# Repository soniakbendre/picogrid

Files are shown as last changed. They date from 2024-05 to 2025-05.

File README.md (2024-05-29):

# Picogrid

[Maitreyee Marathe](maitreyeemarathe23@gmail.com), [Varun Balan](varunbalan30@gmail.com), Prof. Giri Venkataramanan   
University of Wisconsin-Madison

## Overview
The Picogrid is a low-cost low-power experimental platform for energy access and energy management modeling needs. The Picogrid platform consists of three layers, viz., Pico boards, a cloud dashboard, and a remote node as seen in the image below. 

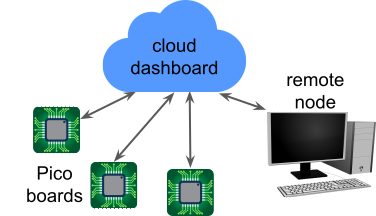
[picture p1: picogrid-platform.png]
Picogrid Platform


These layers together form a small benchtop microgrid or a "picogrid" and emulate their real-world counterparts. Pico boards emulate prosumer households. The remote node emulates a load serving entity, DERMS (distributed energy resource management system), or a microgrid operator which can provide operating set points to the prosumers. The cloud dashboard emulates the data transfer system between the prosumers and the operator.  

## File organization
* pcb-files - contains Gerber files for building Pico boards and add-on modules
* embedded-software - code for Particle microcontroller on the Pico board
* cloud-dashboard - code for setting up cloud dashboard
* remote-node - contains sample code for sending setpoints from a remote node to the cloud dashboard

## Citation
Link and citation for our publication: [Picogrid: An experimental platform for prosumer microgrids](https://ieeexplore.ieee.org/abstract/document/10362891)   
```
@inproceedings{marathe2023picogrid,   
  title={Picogrid: An experimental platform for prosumer microgrids},   
  author={Marathe, Maitreyee and Venkataramanan, Giri},   
  booktitle={2023 IEEE Energy Conversion Congress and Exposition (ECCE)},   
  pages={718--725},   
  year={2023},   
  organization={IEEE}   
}
```

## Acknowledgments
We would like to thank Gabriela
Setyawan, Savannah Ahnen, and Shreya Mukherjee for their help in developing and testing the platform. This work was supported by the George Bunn Wisconsin Distinguished Graduate Fellowship provided by the University of Wisconsin-Madison and the Wisconsin Electric Machines and Power Electronics Consortium.

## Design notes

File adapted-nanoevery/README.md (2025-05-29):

# adapted-nanoevery

This firmware project was created using [Particle Developer Tools](https://www.particle.io/developer-tools/) and is compatible with all [Particle Devices](https://www.particle.io/devices/).

Feel free to replace this README.md file with your own content, or keep it for reference.

## Table of Contents
- [Introduction](#introduction)
- [Prerequisites To Use This Template](#prerequisites-to-use-this-repository)
- [Getting Started](#getting-started)
- [Particle Firmware At A Glance](#particle-firmware-at-a-glance)
  - [Logging](#logging)
  - [Setup and Loop](#setup-and-loop)
  - [Delays and Timing](#delays-and-timing)
  - [Testing and Debugging](#testing-and-debugging)
  - [GitHub Actions (CI/CD)](#github-actions-cicd)
  - [OTA](#ota)
- [Support and Feedback](#support-and-feedback)
- [Version](#version)

## Introduction

For an in-depth understanding of this project template, please refer to our [documentation](https://docs.particle.io/firmware/best-practices/firmware-template/).

## Prerequisites To Use This Repository

To use this software/firmware on a device, you'll need:

- A [Particle Device](https://www.particle.io/devices/).
- Windows/Mac/Linux for building the software and flashing it to a device.
- [Particle Development Tools](https://docs.particle.io/getting-started/developer-tools/developer-tools/) installed and set up on your computer.
- Optionally, a nice cup of tea (and perhaps a biscuit).

## Getting Started

1. While not essential, we recommend running the [device setup process](https://setup.particle.io/) on your Particle device first. This ensures your device's firmware is up-to-date and you have a solid baseline to start from.

2. If you haven't already, open this project in Visual Studio Code (File -> Open Folder). Then [compile and flash](https://docs.particle.io/getting-started/developer-tools/workbench/#cloud-build-and-flash) your device. Ensure your device's USB port is connected to your computer.

3. Verify the device's operation by monitoring its logging output:
    - In Visual Studio Code with the Particle Plugin, open the [command palette](https://docs.particle.io/getting-started/developer-tools/workbench/#particle-commands) and choose "Particle: Serial Monitor".
    - Or, using the Particle CLI, execute:
    ```
    particle serial monitor --follow
    ```

4. Uncomment the code at the bottom of the cpp file in your src directory to publish to the Particle Cloud! Login to console.particle.io to view your devices events in real time.

5. Customize this project! For firmware details, see [Particle firmware](https://docs.particle.io/reference/device-os/api/introduction/getting-started/). For information on the project's directory structure, visit [this link](https://docs.particle.io/firmware/best-practices/firmware-template/#project-overview).

## Particle Firmware At A Glance

### Logging

The firmware includes a [logging library](https://docs.particle.io/reference/device-os/api/logging/logger-class/). You can display messages at different levels and filter them:

```
Log.trace("This is trace message");
Log.info("This is info message");
Log.warn("This is warn message");
Log.error("This is error message");
```

### Setup and Loop

Particle projects originate from the Wiring/Processing framework, which is based on C++. Typically, one-time setup functions are placed in `setup()`, and the main application runs from the `loop()` function.

For advanced scenarios, explore our [threading support](https://docs.particle.io/firmware/software-design/threading-explainer/).

### Delays and Timing

By default, the setup() and loop() functions are blocking whilst they run, meaning that if you put in a delay, your entire application will wait for that delay to finish before anything else can run. 

For techniques that allow you to run multiple tasks in parallel without creating threads, checkout the code example [here](https://docs.particle.io/firmware/best-practices/firmware-template/).

(Note: Although using `delay()` isn't recommended for best practices, it's acceptable for testing.)

### Testing and Debugging

For firmware testing and debugging guidance, check [this documentation](https://docs.particle.io/troubleshooting/guides/build-tools-troubleshooting/debugging-firmware-builds/).

### GitHub Actions (CI/CD)

This project provides a YAML file for GitHub, automating firmware compilation whenever changes are pushed. More details on [Particle GitHub Actions](https://docs.particle.io/firmware/best-practices/github-actions/) are available.

### OTA

To learn how to utilize Particle's OTA service for device updates, consult [this documentation](https://docs.particle.io/getting-started/cloud/ota-updates/).

Test OTA with the 'Particle: Cloud Flash' command in Visual Studio Code or the CLI command 'particle flash'!

This firmware supports binary assets in OTA packages, allowing the inclusion of audio, images, configurations, and external microcontroller firmware. More details are [here](https://docs.particle.io/reference/device-os/api/asset-ota/asset-ota/).

## Support and Feedback

For support or feedback on this template or any Particle products, please join our [community](https://community.particle.io)!

## Version

Template version 1.0.2

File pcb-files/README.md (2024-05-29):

## Pico board PCB
The image below shows the Pico board with the major sections labelled.   
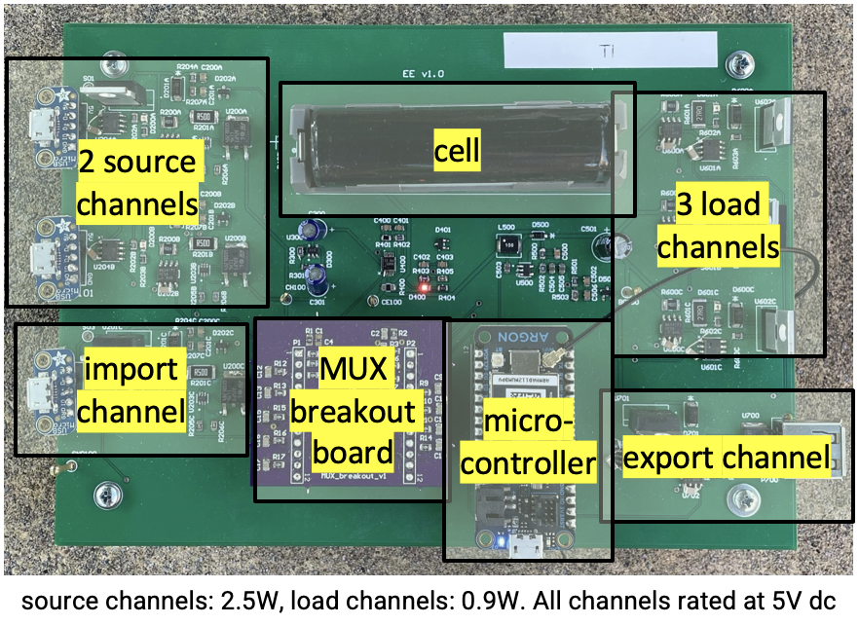
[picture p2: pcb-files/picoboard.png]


## File Organization
* pico-board - files for the Pico board
* mux-breakout - files for the MUX breakout board that is plugged into the Pico board
* junction-board - files for the board used to interconnect Pico boards

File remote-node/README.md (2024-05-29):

The remote node can be any system with an internet connection, not necessarily co-located with the Pico boards.
* send-setpoints.jl - contains sample code in Julia that can be implemented on a remote node to send setpoints to a Pico board

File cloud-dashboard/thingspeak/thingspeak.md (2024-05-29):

To use Mathworks ThingSpeak to develop the cloud dashboard:
* Each ThingSpeak channel can store and display up to 8 fields. Create multiple channels per Pico board if more than 8 fields are needed.
* The write API keys of the channels need to be added to the embedded code for Pico boards to send data to the channel. 
* If Pico boards need to read data from channels, read API keys of the channels are to be added to the embedded code.

More information can be found [here](https://www.mathworks.com/help/thingspeak/).

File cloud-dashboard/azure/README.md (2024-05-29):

This platform is a web application developed with Python (+ [Flask](https://flask.palletsprojects.com/en/3.0.x/)) which interacts with [Particle Argon](https://docs.particle.io/argon/) boards (microcontrollers used in our hardware platform) and [Microsoft Azure](https://azure.microsoft.com/en-us) (the cloud provider used to develop to develop the platform)

## Folder structure
- **app.py**: the main backend code logic which decides what parts of the app the user sees based on user interaction
- **requirements.txt**: list of all the packages that were used in the project. Will use `pip` to download all the packages at once
- **static**: a temporary store to hold the data which the user retrieves and the plots that are generated (the files within these are deleted on each refresh of the app)
- **templates**: HTML pages with [Jinja](https://jinja.palletsprojects.com/en/3.1.x/) templating to dynamically show content based on user interaction with platform

## Cloud Dashboard Screenshots
The image below shows the data retrieval page of the dashboard. Users can get data out from specific Pico boards based on the time frames of their experiment in CSV format for further analysis.   
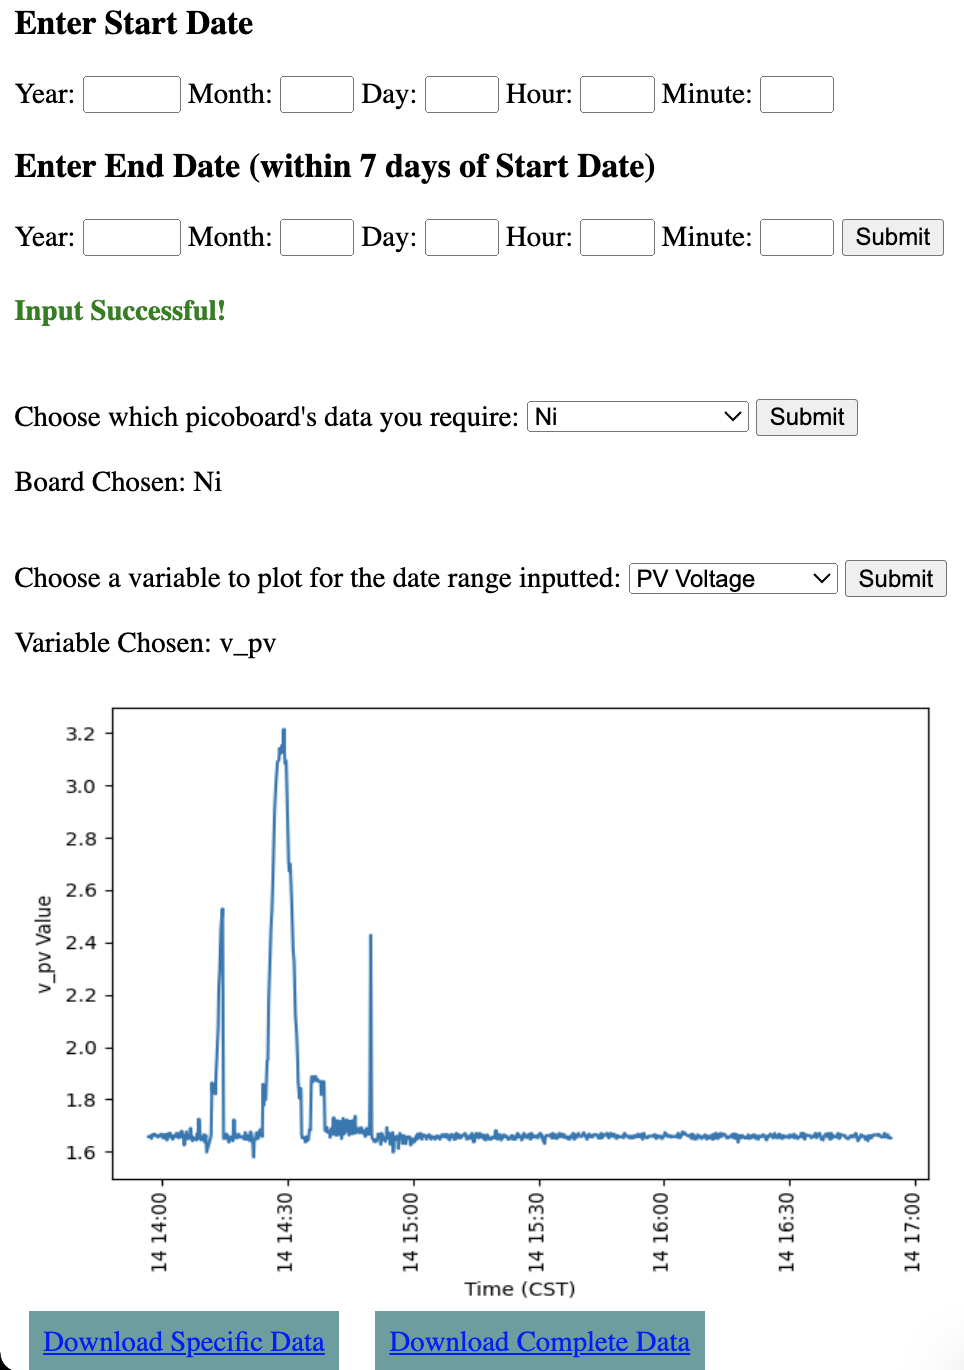
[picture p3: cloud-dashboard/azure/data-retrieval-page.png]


The image below shows the page that can be used to send setpoints (such as thresholds to actuate loads and sources) from the dashboard to the Pico boards. This enables users to make dynamic changes with minimal latency during experiments.   
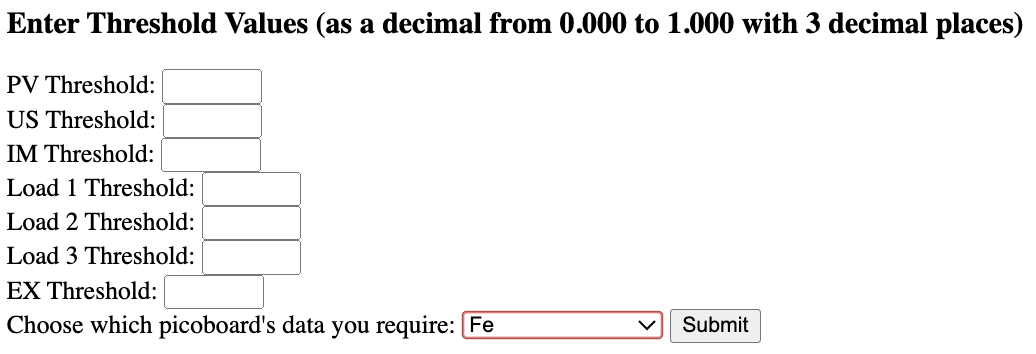
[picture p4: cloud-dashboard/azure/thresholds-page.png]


## Setup
1. After downloading the code and [having pip installed](https://pypi.org/project/pip/), navigate to the folder in Terminal / PowerShell and run `pip install -r requirements.txt` to download all packages
2. Set up Azure IoT Hub and a Particle Integration to connect the Particle Argon to Azure using these [instructions](https://docs.particle.io/community/photon-maker-kit-workshop/ch3/)
3. Create an Azure Blob Storage Account using these [instructions](https://learn.microsoft.com/en-us/azure/storage/common/storage-account-create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) - make sure that public read access is not allowed
4. Route messages that come into Azure IoT Hub to the Blob Storage following these [instructions](https://azure.microsoft.com/en-us/blog/route-iot-device-messages-to-azure-storage-with-azure-iot-hub/) and this [reference](https://learn.microsoft.com/en-us/azure/iot-hub/tutorial-routing?tabs=portal)
5. Ensure that the messages are sent to Azure Blob Storage in JSON form using this [document](https://learn.microsoft.com/en-us/azure/iot-hub/tutorial-routing?tabs=portal#route-to-a-storage-account)
6. Grant read access to the Azure Storage Blob using an Azure Role Assignment in Azure Access Control (IAM). Add the `Storage Blob Data Reader` for the users that need to access the data
7. Create an Azure App Service to host the Python Flask App using these [instructions](https://learn.microsoft.com/en-us/azure/app-service/quickstart-python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)
8. Create a Managed Identity for the App Service in the Settings -> Identity Pane of the App Service and obtain the Object ID. Add this managed identity as an authorized `Storage Blob Data Reader` for the Azure Storage Blob (ensure secure access of the )
9. Go to Particle Access Tokens [Docs](https://docs.particle.io/reference/cloud-apis/access-tokens/) and generate an access token that does not expire. Create a secret in Azure Key Vault using instructions [here](https://learn.microsoft.com/en-us/azure/key-vault/secrets/quick-create-portal) and store the access token as a secret. You will need to ensure that `Key Vault Secrets User` role assignment (in the IAM pane) is added for the App Service Managed Identity + any users that will modify / add the secret.
10. In `config.py` follow the TODO tasks to populate the fields for the application to pull from the correct resources and credentials

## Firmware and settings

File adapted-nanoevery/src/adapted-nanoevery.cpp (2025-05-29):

// electric Little Free Library - Particle Boron Version
// Author: Adapted by Sukriti 
// Platform: Particle Boron
// Logs battery + temperature data via Serial1 to OpenLog or SD system
 
#include "Particle.h"
 
// -------- Pin Definitions --------
const int temperature_pin = A0;
const int iLoad_pin = A1;     // Not used right now
const int iBatt_pin = A2;
const int vBatt_pin = A3;
const int door_pin = A4;      // Replace with D2/D3 if needed
const int red_pin = D2;
const int green_pin = D3;
 
// -------- Sensor Constants --------
const float sensitivity = 2.5;       // mA/mV
const float Vref_Batt = 2480.0;      // mV @ 0 current
const float v_low = 11.5;            // Low voltage threshold (V)
const float v_high = 12.0;           // High voltage threshold (V)
const int avgSamples = 10;           // Number of sensor readings to average
const int delayTime = 2;             // ms between samples
const int logTime = 5000;            // ms between logs
 
// -------- Runtime Variables --------
int iBatt_value = 0;
int temperature_value = 0;
int vBatt_value = 0;
 
void setup() {
  Serial.begin(9600);     // USB serial
  Serial1.begin(9600);    // TX/RX for OpenLog
 
  pinMode(temperature_pin, INPUT);
  pinMode(iLoad_pin, INPUT);
  pinMode(iBatt_pin, INPUT);
  pinMode(vBatt_pin, INPUT);
  pinMode(door_pin, INPUT);
  pinMode(red_pin, OUTPUT);
  pinMode(green_pin, OUTPUT);
 
  Time.zone(-5); // Set your local time zone (e.g. CST = -5, (for now I have set)  adjust as needed)
  waitUntil(Particle.connected); // Ensure time is synced
}
 
void loop() {
  // ---------- Sensor Averaging ----------
  iBatt_value = 0;
  temperature_value = 0;
  vBatt_value = 0;
 
  for (int i = 0; i < avgSamples; i++) {
    iBatt_value += analogRead(iBatt_pin);
    temperature_value += analogRead(temperature_pin);
    vBatt_value += analogRead(vBatt_pin);
    delay(delayTime);
  }
 
  iBatt_value /= avgSamples;
  temperature_value /= avgSamples;
  vBatt_value /= avgSamples;
 
  // ---------- Convert to Physical Units ----------
 
  // Battery current
  float batt_voltage_mV = iBatt_value * 0.805;  // 3.3V / 4095 * 1000
  float iBatt = (batt_voltage_mV - Vref_Batt) * sensitivity;
 
  // Temperature (LM35 style sensor)
  float temp_voltage = temperature_value * 3.3 / 4095.0; // in volts
  float temperature = (temp_voltage - 0.5) * 100.0;       // in °C
 
  // Battery voltage (via voltage divider)
  float adc_voltage = vBatt_value * 3.3 / 4095.0; // ADC voltage
  float vBatt = adc_voltage * 5.5;               // Apply gain from voltage divider
 
  // ---------- LED Indicator Logic ----------
  if (vBatt >= v_high) {
    digitalWrite(green_pin, HIGH);
    digitalWrite(red_pin, LOW);
  } else if (vBatt <= v_low) {
    digitalWrite(green_pin, LOW);
    digitalWrite(red_pin, HIGH);
  }
 
  // ---------- Time Logging ----------
  String timestamp = Time.format(Time.now(), "%Y-%m-%d %H:%M:%S");
 
  String dataLine = timestamp + ", " +
                    "Battery Current (mA): " + String(iBatt, 2) + ", " +
                    "Temperature (C): " + String(temperature, 2) + ", " +
                    "Battery Voltage (V): " + String(vBatt, 2);
 
  Serial.println(dataLine);
  Serial1.println(dataLine); // Send to OpenLog
 
  delay(logTime - (delayTime * avgSamples));
}

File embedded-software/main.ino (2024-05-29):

/*
 * Project Picogrid
 * Description: Embedded code for Pico boards
 * Author: Maitreyee Marathe, Varun Balan
 */


#include "device_config.h"
#include "functions.h"
#include <string>

// If cloud dashboard is developed using ThingSpeak:
// #include "ThingSpeak.h"
// TCPClient client;

// Define variables for sensor reading and miscellaneous operations
float v_pv = 0.0;
float i_pv = 0.0;
float v_us = 0.0;
float i_us = 0.0;
float v_im = 0.0;
float i_im = 0.0;
float v_cell = 0.0;
float i_cell = 0.0;
float v_boost = 0.0;
float i_lo1 = 0.0;
float i_lo2 = 0.0;
float i_lo3 = 0.0;
float i_ex = 0.0;
float i_cell_estimated = 0.0;
float charge_soc = -1.0;
unsigned long int last_soc_update, simulation_start_time, last_duty_update;
// Define duty cycles if implementing variable power at sources/loads
// int pv_duty[<>] = {<>};
// int lo1_duty[<>] = {<>};
// int lo2_duty[<>] = {<>};
int duty_index = 0;
float time_step = 10; // in seconds
device d = get_device_data(); // Get device data

// If using cloud dashboard developed using Azure
// // Integration for "azure-cloud-data" created in Particle Dashboard for the device
// char event[17] = "azure-cloud-data";
// // Function which runs when thresholds are sent to picoboard
// int get_setpoints(String data) {
//  // Process the received_data here
//  Particle.publish("setpoints_received", data, PRIVATE);
//  return 0;
//}


void setup() {
  
  // Pin mappings are defined in device_config.h

  // Define whether pins are input/output
  pinMode(COM_IO, INPUT);
  pinMode(S0, OUTPUT);
  pinMode(S1, OUTPUT);
  pinMode(S2, OUTPUT);
  pinMode(S3, OUTPUT);
  pinMode(LO1_GATE, OUTPUT);
  pinMode(LO2_GATE, OUTPUT);
  pinMode(LO3_GATE, OUTPUT);
  pinMode(EX_GATE, OUTPUT);
  pinMode(PV_GATE, OUTPUT);
  pinMode(US_GATE, OUTPUT);
  pinMode(IM_GATE, OUTPUT);

  charge_soc = compute_initial_soc(d.cell_voltage_p[0],d.cell_voltage_p[1],d.cell_voltage_p[2]);
  last_soc_update = Time.now();
  simulation_start_time = Time.now();
  last_duty_update = -1;
  
  // If cloud dashboard is developed using ThingSpeak:
  // ThingSpeak.begin(client);  
  
  // If cloud dashboard is developed using Azure:
  // // register the cloud function for obtaining thresholds
  // Particle.function("get_thresholds", get_thresholds);

}


void loop() {

  // To ensure that code executes once every time_step seconds
  if (duty_index > 0)
    if (Time.now() - last_duty_update < time_step)
      delay((time_step - (Time.now() - last_duty_update))*1000);
  
  // Digital write
  // Switch states in the order pv, us, im, lo1, lo2, lo3, ex
  // switch_state s = {true, false, false, true, false, false, false};
  // actuate(s);

  // Combination of analog and digital write
  // analogWrite(PV_GATE, 255-pv_duty[duty_index]);
  // digitalWrite(US_GATE, 1);
  // digitalWrite(IM_GATE, 1);
  // analogWrite(LO1_GATE, lo1_duty[duty_index]);
  // digitalWrite(LO2_GATE, 0);
  // digitalWrite(LO3_GATE, 0);
  // digitalWrite(EX_GATE, 1);
  
  last_duty_update = Time.now();

  // Reading sensors
  v_cell = read_voltage(V_CELL_CODE,d.cell_voltage_p[0],d.cell_voltage_p[1],d.cell_voltage_p[2]);
  i_cell = read_cellcurrent(I_CELL_CODE);
  v_pv = read_voltage(V_PV_CODE,0,1.1,0);
  i_pv = read_current(I_PV_CODE,d.current_p1[0],d.current_p2[0]);
  v_us = read_voltage(V_US_CODE,0,1.1,0);
  i_us = read_current(I_US_CODE,d.current_p1[1],d.current_p2[1]);
  v_im = read_voltage(V_IM_CODE,0,1.1,0);
  i_im = read_current(I_IM_CODE,d.current_p1[2],d.current_p2[2]);
  v_boost = read_voltage(V_BOOST_CODE,0,1.1,0);
  i_lo1 = read_current(I_LO1_CODE,d.current_p1[3],d.current_p2[3]);
  i_lo2 = read_current(I_LO2_CODE,d.current_p1[4],d.current_p2[4]);
  i_lo3 = read_current(I_LO3_CODE,d.current_p1[5],d.current_p2[5]);
  i_ex = read_current(I_EX_CODE,d.current_p1[6],d.current_p2[6]);

  // Estimating i_cell
  i_cell_estimated = -(i_pv + i_us + i_im) + (5/v_cell)*(1/0.9)*(i_lo1 + i_lo2 + i_lo3 + i_ex);

  // Updating soc
  charge_soc = update_charge_soc(charge_soc, i_cell_estimated, d.c_max, last_soc_update); 
  last_soc_update = Time.now();

  // To ensure that cloud dashboard is updated once every two timesteps
  if (duty_index % 2 == 0)
  {  
    ////////////////////////////////////////   
    // Send sensor data to cloud dashboard
    ////////////////////////////////////////
    // If cloud dashboard is developed using ThingSpeak:   
    //  // update channel a
    //  ThingSpeak.setField(1,v_cell);
    //  ThingSpeak.setField(2,i_cell);
    //  ThingSpeak.setField(3,v_pv);
    //  ThingSpeak.setField(4,i_pv);
    //  ThingSpeak.setField(5,v_us);
    //  ThingSpeak.setField(6,i_us);
    //  ThingSpeak.setField(7,v_im);
    //  ThingSpeak.setField(8,i_im);
    //  ThingSpeak.writeFields(d.channel_a_number, d.channel_a_writeapikey);
    //  // update channel b
    //  ThingSpeak.setField(1, v_boost);
    //  ThingSpeak.setField(2, i_lo1);
    //  ThingSpeak.setField(3, i_lo2);
    //  ThingSpeak.setField(4, i_lo3);
    //  ThingSpeak.setField(5, i_ex);
    //  ThingSpeak.setField(6, charge_soc);
    //  ThingSpeak.writeFields(d.channel_b_number, d.channel_b_writeapikey);

    // If cloud dashboard is developed using Azure:
    // // Put data in a JSON-like string to send to Azure dashboard
    // char picogrid_data_json[1024];
    // snprintf(picogrid_data_json, sizeof(picogrid_data_json), "{\"v_pv\":%f,\"i_pv\":%f,\"v_us\":%f,\"i_us\":%f,\"v_im\":%f,\"i_im\":%f,\"v_cell\":%f,\"i_cell\":%f,\"v_boost\":%f,\"i_lo1\":%f,\"i_lo2\":%f,\"i_lo3\":%f,\"i_ex\":%f,\"soc\":%f}", v_pv, i_pv, v_us, i_us, v_im, i_im, v_cell, i_cell, v_boost, i_lo1, i_lo2, i_lo3, i_ex, charge_soc);
    // // Send the string using the event created with Azure integration
    // Particle.publish(event, picogrid_data_json, PRIVATE);

    /////////////////////////////////////////////////////////// 
    // Read setpoints from ThingSpeak-based cloud dashboard
    ///////////////////////////////////////////////////////////    
    // setpoint = ThingSpeak.readFloatField(d.channel_setpoints_number, 1, d.channel_setpoints_readapikey);

  }

  duty_index = duty_index + 1;

}

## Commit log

2024-05-29 Add files (#1)
    * adding files
    * Update README.md
    * Add files via upload
    * Update README.md
    * Add pico board PCB image
    * Update README.md
    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
    [EE_v1.GBL, EE_v1.GBO, EE_v1.GBP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]
2025-05-28 Started trying to test temperature sensor output
2025-05-28 Changed temperature and timestamp settings in sd
